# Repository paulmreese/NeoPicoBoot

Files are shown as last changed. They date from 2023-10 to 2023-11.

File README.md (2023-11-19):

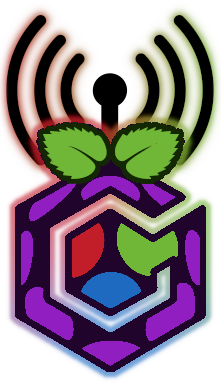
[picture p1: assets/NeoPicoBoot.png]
NeoPicoBoot Logo. A cubic raspberry logo with an antenna glowing red, green and blue


# NeoPicoBoot: NeoPixel + PicoBoot
This is an IPL replacement modchip for Nintendo GameCube. It's also a WiFi Access Point hosting responsive RGB control. It's open source, cheap, and easy to install.

## Features
* open source, easy to install
* uses $6 Raspberry Pi Pico W board
* RGB control for your controller ports and power LED
* easy-to-access NeoPixel web controls via Captive Portal
* boots any DOL app of your choice

<p align="center">
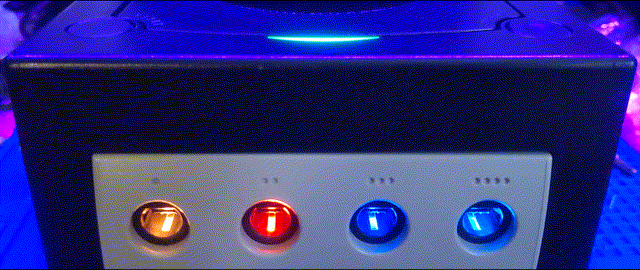
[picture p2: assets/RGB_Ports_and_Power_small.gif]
A zoomed-in view of a modded GameCube cycling a rainbow of colors in from the controller ports and power LED
  
</p>

## Installation guide

The complete installation guide has been moved to [a separate document](/INSTALLATION.md).

**A diode must be correctly installed between 5V and VSYS to prevent backflow. Connecting power to the USB port without a diode will destroy the power board, at minimum. Please mod carefully.**

Other than the NeoPixels being added, and **3V3** being swapped for **VSYS** from the 5V rail of the controller ports(through [a Schottky diode](https://www.amazon.com/dp/B0BYWPMRT1)), the wiring works exactly like the original. So, if you need any additional help you can head over to [the PicoBoot wiki](https://github.com/webhdx/PicoBoot/wiki) for [the PicoBoot Installation guide](../../wiki/Installation-guide).

Additionally, you can check the PicoBoot Discord Server to get support and discuss new features:



## Usage guide

The controls are designed to be as intuitive as possible. Take a look at the [Usage guide](USAGE.md) if you have any questions(or if you want to customize your network name or security).

## 3D Printed Parts
Printing these `STL` files makes for a much simpler installation process, but neither is necessary.

* [PicoBoot Mount for the Nintendo Gamecube](https://www.thingiverse.com/thing:5482506) - This mounts the Pico W onto the controller port board. While other mounts exist, this one is convenient for 2 reasons:
    1. The wires can exit the motherboard towards the controller ports, without deforming the RF shielding.
    2. The NeoPixels can be closer to the Pico W itself, with shorter wires.
* [NeoPixel alignment bracket](/assets/NeoPixel_Bracket.stl) - This bracket helps to align all of the controller port NeoPixels with the correct spacing. It will only install below the controller ports, if you have a normally installed battery. This can be printed in PLA and hot-glued into place.
  * This model was designed for a 0.4mm nozzle and 0.2mm layer height.

## Video guides and features overview

- [PicoBoot Modchip Will Unleash The POWER of Your Nintendo GAMECUBE! | Installation Guide and Overview](https://www.youtube.com/watch?v=qwL4ZSa0xMo) by [MachoNachoProductions](https://www.youtube.com/c/MachoNachoProductions)
- [This new Gamecube Modchip is a GAMECHANGER - PicoBoot](https://www.youtube.com/watch?v=lfMTLEM0yeQ) by [RockerGaming](https://www.youtube.com/c/RockerGaming)
- [$5 Gamecube IPL Modchip?! Picoboot Dol-001 + Dol-101 Installation / Setup / Showcase](https://www.youtube.com/watch?v=W_9-mSBMBJ4) by [ModzvilleUSA!](https://www.youtube.com/c/ModzvilleUSA)
- [PicoBoot GameCube custom mod chip - make and install your own chip with a Raspberry Pi Pico](https://youtu.be/rDrosSd-nDc) by [Joe Bleeps](https://www.youtube.com/@JoeBleeps)
- [RGB LED Mod Tutorial/ How to/ guide - Gamecube, Saturn, N64, SNES, and More!](https://youtu.be/1XUOI1c_viQ?si=Boch__JV7q4JWGpH) - This is a general RGB installation guide, but it does include GameCube

## Acknowledgements

Some parts of this project use GPL-2.0 licensed code from:
 * https://github.com/webhdx/PicoBoot
 * https://github.com/redolution/iplboot

Some parts of this project use MIT licensed code from:
 * https://github.com/sysprogs/PicoHTTPServer

Some parts of this project use LGPL-3.0 licensed code from:
 * https://github.com/martinkooij/pi-pico-adafruit-neopixels
 * https://github.com/adafruit/Adafruit_NeoPixel

## Hall of Fame

These are the people who made PicoBoot possible:
* [webhdx](https://github.com/webhdx) - All credit for the [PicoBoot](https://github.com/webhdx/PicoBoot) goes here. Consider being their [Sponsor](https://github.com/sponsors/webhdx)

* #gc-forever crew: [Extrems](https://github.com/Extrems), [novenary](https://github.com/9ary), [emu_kidid](https://github.com/emukidid) and others
* [tmbinc](https://github.com/tmbinc) - he started it all 🙏
* happy_bunny - [webhdx] started [webhdx's] research with his great writeup on [Shuriken Attack](https://www.retro-system.com/shuriken_attack.htm)
* PicoBoot beta testers: [seewood](https://github.com/seewood), [MethodOrMadness](https://github.com/MethodOrMadness), [renanbianchi](https://github.com/renanbianchi)
* content creators: [MachoNachoProductions](https://www.youtube.com/c/MachoNachoProductions), [RockerGaming](https://www.youtube.com/c/RockerGaming), [ModzvilleUSA!](https://www.youtube.com/c/ModzvilleUSA)
* people who sponsored [PicoBoot](https://github.com/webhdx/PicoBoot)
* every PicoBoot enjoyer - it's all about you after all 😉

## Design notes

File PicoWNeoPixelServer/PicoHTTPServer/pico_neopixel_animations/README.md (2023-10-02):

# Adafruit NeoPixel Animation Library for Pi PICO C/C++ SDK

Wrapper library for the Pi Pico Port of the Adafruit Library in a C/C++ SDK environment.
Built according to SDK standards as an INTERFACE library. In addition to functions and capabilities offered in the [original repo](https://github.com/martinkooij/pi-pico-adafruit-neopixels), this library allows the user to choose a custom animation order for a given NeoPixel(WS2812, etc.) strand, independent of the electrical order of the NeoPixel wiring. This enables easy control from an extrnal WiFi or Bluetooth library.

Friendly usage of pio statemachine implementations: Any NeoPixel object seizes sm and pio program space in a friendly, cooperative way.

The source library can be found in the main folder of this project (pico_neopixel_animations subdirectory). Adapt your project Makefile by using the command "add_subdirectory", then adding adding pico_neopixel_animations to the libraries of your project.

## Installation
Clone this repo to you local system using
````
git clone https://github.com/paulmreese/pico_neopixel_animations
````

## Building Examples
If the Pico SDK is installed according to its documentation, then the original examples should easily build.

Linux/Mac
````
cd pico_neopixel_animations/pi-pico-adafruit-neopixels/example
mkdir build && cd build
cmake ..
make
````
Windows
````
cd pico_neopixel_animations/pi-pico-adafruit-neopixels/example
mkdir build && cd build
cmake .. -G "NMake Makefiles"
nmake
````

The examples that work are `simple`, `strandtest_wheels` and ....
for the owner of the Maker PI PICO board of Cytron the example `onboard_cytron` that gives a nice colorful show on the built in NeoPixel (a strand of length 1 on PIN 28).

## Code Setup
NeoPixels may be connected to any GPIO pin. Once you are confident in the wiring and pin choices for your NeoPixel strand, you'll need to construct a `NeoPixelStrip` object to send instructions to, as shown:
1. Declare your LED pin, count(amount of LEDs), and pixel order. The `PIXEL_ORDER` defines the order the NeoPixels should follow, relative to the way they are electrically sequenced(The first NeoPixel of the electrical sequence would automatically be number "0", next is "1", etc.). **The string should terminate with a trailing space!!**
````
uint16_t LED_PIN =  28;
uint16_t LED_COUNT = 5;
std::string PIXEL_ORDER = "3 2 1 0 4 ";
````
2. Declare our `NeoPixelStrip` object(name `npStrip`):
````
NeoPixelStrip npStrip(LED_COUNT, LED_PIN, PIXEL_ORDER);
````
3. Send desired animation instructions:
````
npStrip.test_loop();
````

## Library documentation
This library is intended to provide animation functions that are easy to access from an external project. The available functions fall generally into two types: animation functions and their helper functions. An explanation of the purpose of each individual function is provided in the [header file of this project](pico_neopixel_animations.h)

## Resources specific to the Adafruit Neopixel library
See [the Adafruit Neopixel library documentation](https://github.com/adafruit/Adafruit_NeoPixel) for more information specific to it.

## Resources specific to the Adafruit Pi Pico port
[The original repo](https://github.com/martinkooij/pi-pico-adafruit-neopixels) contains more specific implementation details.

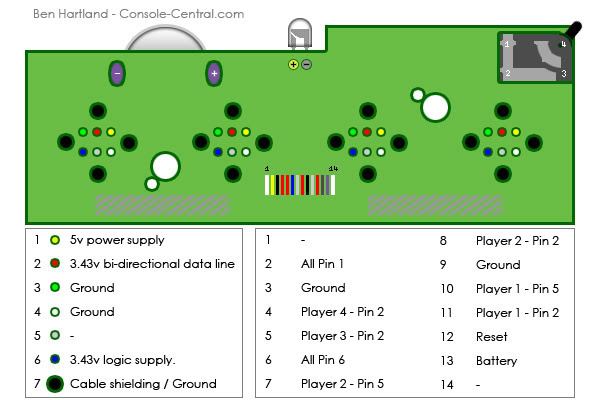
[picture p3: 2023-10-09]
assets/gamecubecontrollerboard.jpeg

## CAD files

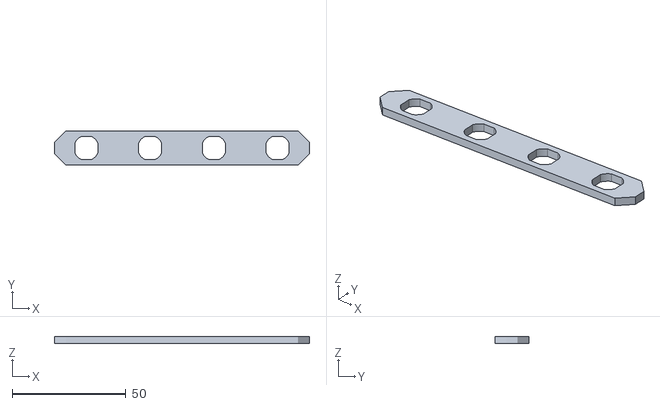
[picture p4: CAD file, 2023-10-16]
assets/NeoPixel_Bracket.stl
112.0 x 15.0 x 3.00

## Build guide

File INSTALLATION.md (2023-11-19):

# NeoPicoBoot: NeoPixel + PicoBoot

## Installation guide

<p align="center">
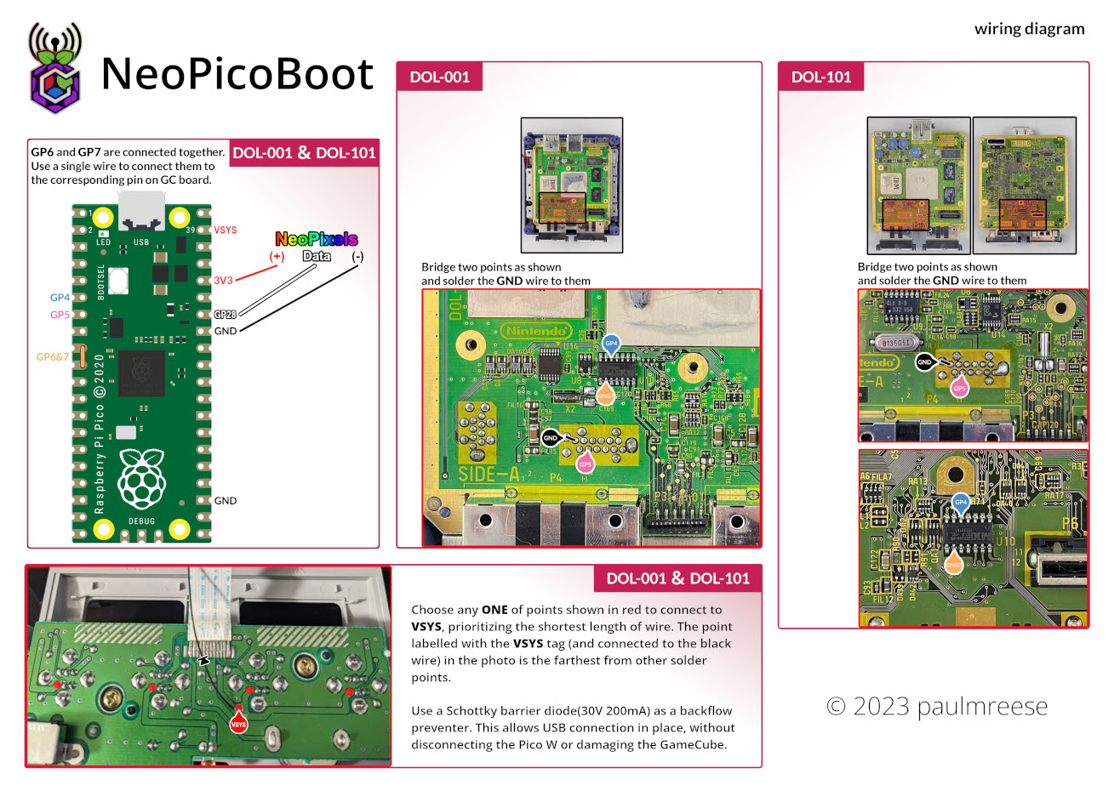
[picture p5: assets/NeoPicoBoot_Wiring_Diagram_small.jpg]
NeoPicoBoot Wiring Diagram
  
  <i>
    A visual installation guide to show wiring connections
  </i>
</p>

**A diode must be correctly installed between 5V and VSYS to prevent backflow. Connecting power to the USB port without a diode will destroy the power board, at minimum. Please mod carefully.**

This should be enough information to guide someone through a basic installation. [A larger version of the image](/assets/NeoPicoBoot_Wiring_Diagram.jpg) is also included with this repo. This wiring incorporates [a method mentioned in an issue on the original PicoBoot Repo](https://github.com/webhdx/PicoBoot/issues/75#issuecomment-1539225503), which wires power into the **VSYS** pin of the Pico W through [a Schottky diode](https://www.amazon.com/dp/B0BYWPMRT1), instead of being directly wired to the **3V3** pin.

According to the [Raspberry Pi Pico W Datasheet](https://datasheets.raspberrypi.com/picow/pico-w-datasheet.pdf):
> VSYS is the main system input voltage, which can vary in the allowed range 1.8V to 5.5V, and is used by the on-board SMPS to generate the 3.3V for the RP2040 and its GPIO.

> 3V3 is the main 3.3V supply to RP2040 and its I/O, generated by the on-board SMPS. This pin can be used to power external circuitry (maximum output current will depend on RP2040 load and VSYS voltage; it is recommended to keep the load on this pin under 300mA).

### RGB
As for the NeoPixels(WS2812, etc), this [video shows exactly how to mod your controller port board to add the NeoPixels](https://youtu.be/1XUOI1c_viQ?si=Boch__JV7q4JWGpH)
<p align="center">
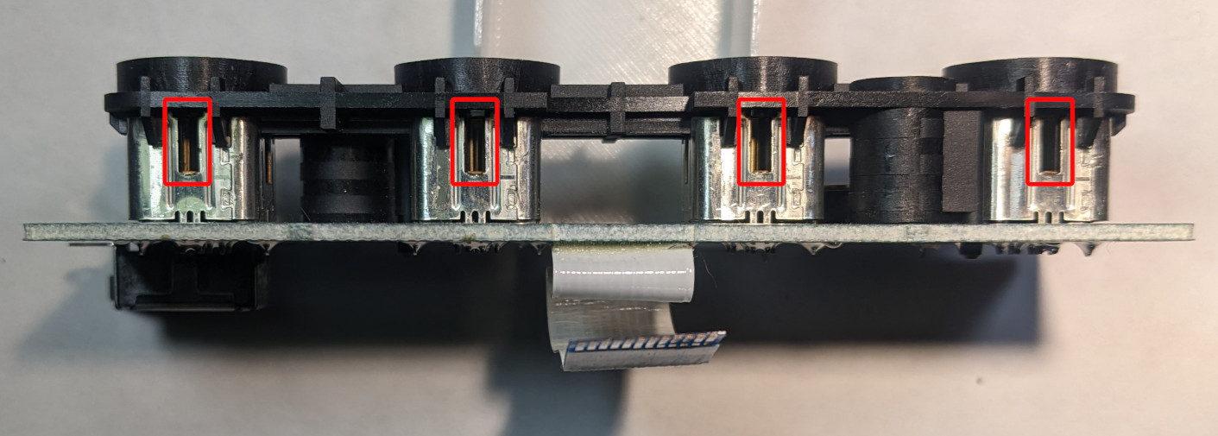
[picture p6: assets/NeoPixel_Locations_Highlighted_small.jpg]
View of the GameCube controller port PCB from below, with the center retaining pins removed(highlighted in red).
  
  <i>GameCube controller ports from below, with retaining pins removed</i>
</p>

* [1:04](https://youtu.be/1XUOI1c_viQ?si=35ieH2EPR0lPXH_Q&t=64) - Remove the pins from each port. These pins can be removed from **either** the top *or* the bottom of each controller port. These LEDs can be very bright, so choose based on where you keep your GameCube. I personally use tweezers to snap the bottom ones so that I'm not competing with the battery for space.
<p align="center">
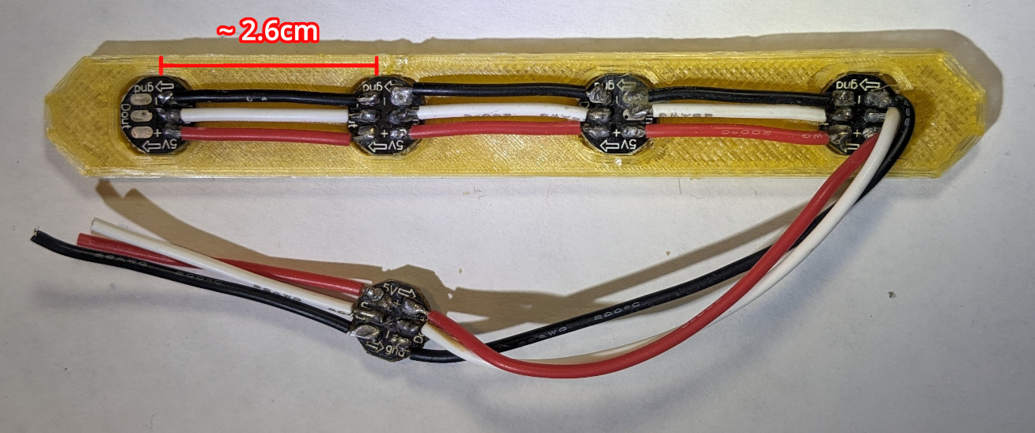
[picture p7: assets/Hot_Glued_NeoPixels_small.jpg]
Five NeoPixels wired together in a chain, with four of them hot-glued into a 3d-printed bracket.
  
  <i>Wired NeoPixels set in their <a href="/assets/NeoPixel_Bracket.stl">3D-printed bracket</a></i>
</p>

* [3:25](https://youtu.be/1XUOI1c_viQ?si=mzvSUIralLa4HMga&t=205) - Create a strand of 5 NeoPixels. Make sure to leave a little bit of slack in the wires between each NeoPixel, especially to the power led and Pico W. Make sure the arrows on your NeoPixels point the same direction, and check continuity on the positive and negative wires regularly!
<p align="center">
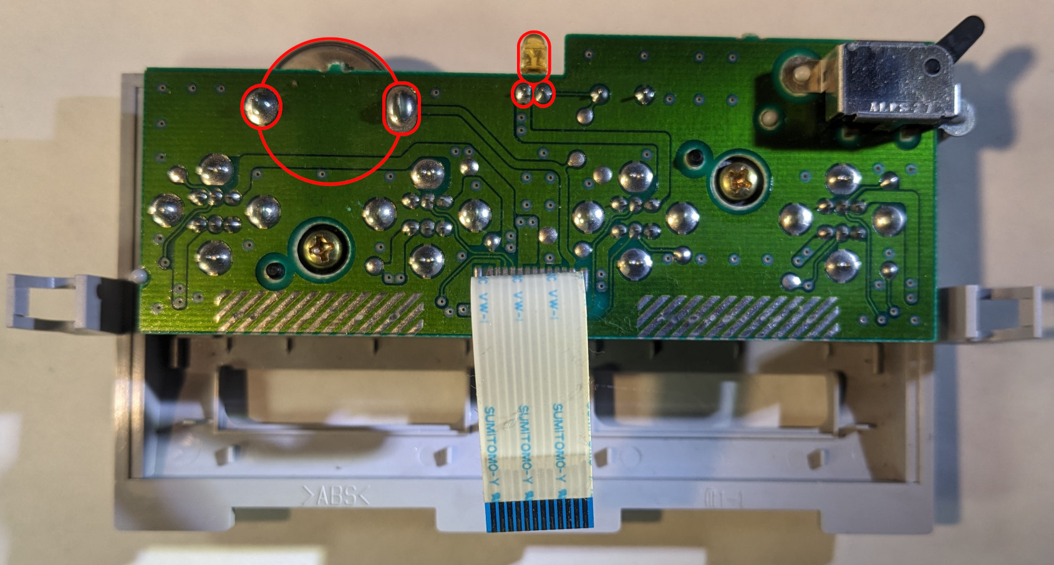
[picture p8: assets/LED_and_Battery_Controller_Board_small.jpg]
View of the GameCube controller port PCB from the back, highlighting the pins of the power LED and Battery
  
  <i>Battery and power LED solder points</i>
</p>

* [5:50](https://youtu.be/1XUOI1c_viQ?si=wtnrG3PIRv7RvrTk&t=350) - Remove stock LED. Optionally, also replace CR2032 Clock Battery. I would highly recommend replacing this battery with a separate battery holder and fresh battery.
<p align="center">
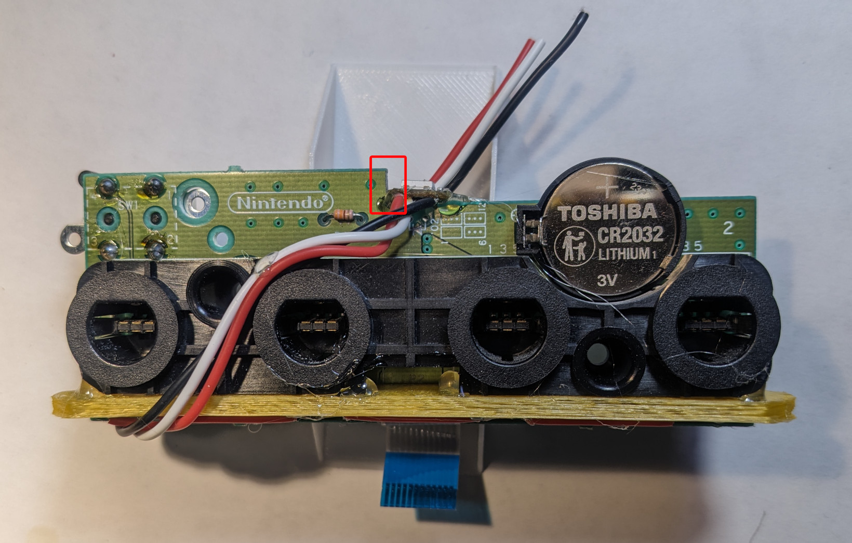
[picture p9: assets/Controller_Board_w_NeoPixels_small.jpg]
View of the GameCube controller port PCB from the front, with the sanded/filed-away area highlighted. A new battery holder with a new battery is shown.
  
  <i>The highlighted area has been sanded away. Note the new battery holder</i>
</p>

* [6:25](https://youtu.be/1XUOI1c_viQ?si=p0bYnIFZQqc9hqtQ&t=385) - Hot glue controller port NeoPixels into place. Make sure they all point the same angle! You can remove the hot glue with rubbing alcohol. I've included [a 3D model of a basic alignment bracket as an STL file](/assets/NeoPixel_Bracket.stl) if you have access to a 3D printer. This bracket will only install below the controller ports, if you have a normally installed battery.

* [8:00](https://youtu.be/1XUOI1c_viQ?si=zBVIya90WfhzKUA-&t=480) - Hot glue Power NeoPixel. In my experience, you often need to seat the power LED lower than shown in the video for it to align correctly with the original light pipe. I recommend seating to the bottom of the notch on the PCB. This can sometimes involve sanding the PCB to the side to fit a NeoPixel.
<p align="center">
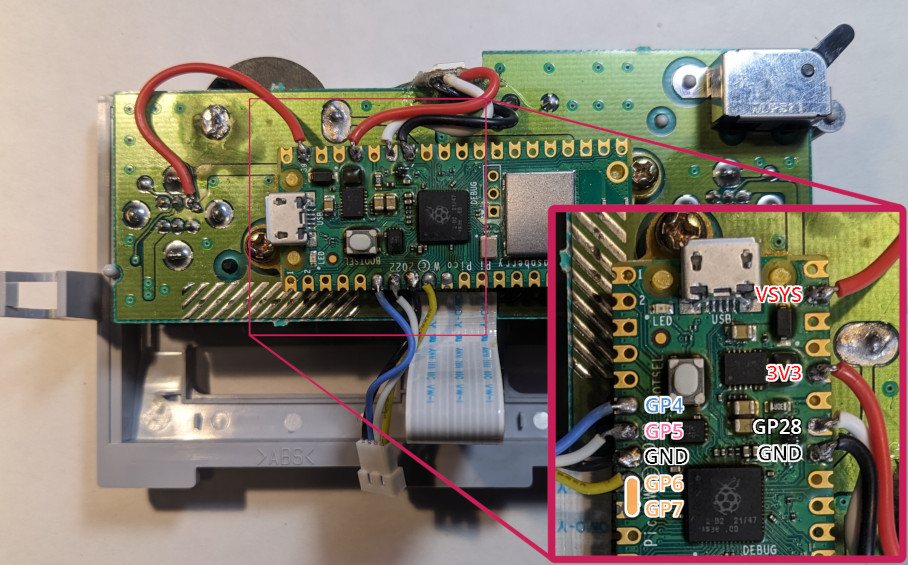
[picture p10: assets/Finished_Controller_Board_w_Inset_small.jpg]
View of the GameCube controller port PCB from the back, with the Pico W wired to the NeoPixels, the 5V rail of GameCube, and wires to connect to the GameCube motherboard
  
  <i>Pico W mounted to the controller port board with wires connecting to the NeoPixels, 5V power, and motherboard(for PicoBoot)</i>
</p>

Other than the NeoPixels being added, and **3V3** being swapped for **VSYS** from the 5V rail of the controller ports, the wiring works exactly like the original. So, if you need any additional help you can head over to [the PicoBoot wiki](https://github.com/webhdx/PicoBoot/wiki) for [the PicoBoot Installation guide](../../wiki/Installation-guide).

Additionally, you can check the PicoBoot Discord Server to get support and discuss new features:



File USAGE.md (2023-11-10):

# Usage Guide

The NeoPicoBoot web interface is designed to be as straightforward to use as possible. This guide explains the features and their usage. If you would like to request additional patterns or animations, please submit a feature request to this repository.

## Network Name and Password

NeoPicoBoot uses the Captive Portal method broadcasting a network as a dedicated WiFi Access Point. By default, this network will have the default SSID of `GC_RGB` and no password.

These values can be altered in [the CMakeLists.txt file in the PicoWNeoPixelServer/PicoHTTPServer directory](https://github.com/paulmreese/NeoPicoBoot/blob/686e2f957be58c4621f378fb9fc77a336fcbb2db/PicoWNeoPixelServer/PicoHTTPServer/CMakeLists.txt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). You can substitute any valid name for the network SSID you prefer. To add a password, just uncomment `set(WIFI_PASSWORD 12345678)` and replace `12345678` with that password. You'll need to recompile the firmware if you change these settings. The remainder of this guide will refer to the default settings.

## Connecting

When you start up the Pico W after installing the firmware(or when you startup your GameCube with the mod installed), a startup animation sequence will display on the NeoPixels. This happens after the PicoBoot code has successfully run. The display occurs as the server is initialized. You can now use any WiFi-enabled device to access the `GC_RGB` network, which will initiate the Captive Portal process. For most modern phones, you'll be given the option to `Sign into network`(or similar wording) as a notification. On many devices the control page will automatically appear upon your attempted connection.

### Troubleshooting Connection

Some devices may notice that this network offers no internet access and balk at any connection attempts. In this case there is often an option to `Connect Anyways` within the network-specific settings. This may require that the device remembers the network for next usage. Please submit any connection issues you encounter to this repo.

## Control

The controls are presented as a responsive web app, and as the result of this approach will differ between different systems. If you encounter any issues interacting with the controls, please let me know!

<p align=center>
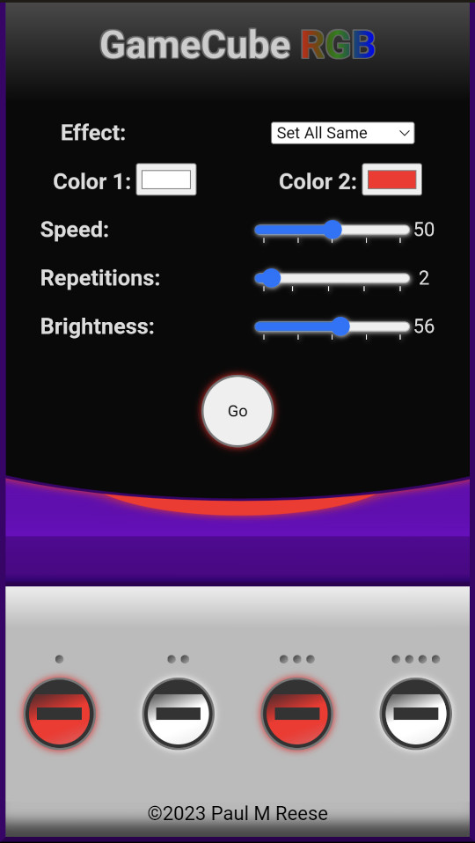
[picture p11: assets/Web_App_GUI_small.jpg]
A screen shot of the GameCube RGB interface of NeoPicoBoot
  
</p>

For any individual LED on the system, you can click or tap the corresponding location to bring up a color picker to set a new color. The color will fade from the current color to the chosen color.

For patterns of animation affecting all NeoPixels, you'll first need to select the relevant animation from the Effect drop-down. This will activate any options that would be used by the particular animation. Next, you'll need to set the desired colors, repetitions, speed, and/or brightness. Once you've chosen your values, click `Go`!

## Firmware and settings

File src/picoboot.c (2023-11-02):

/**
 * Copyright (c) 2022 Maciej Kobus
 * Original code licensed under
 * SPDX-License-Identifier: GPL-2.0-only
 * All additional code licensed under GPL-3.0
 */
#include <stdio.h>
#include "pico/stdlib.h"
//#include "pico/cyw43_arch.h"
#include "hardware/pio.h"
#include "hardware/clocks.h"
#include "hardware/dma.h"
#include "hardware/structs/bus_ctrl.h"
#include "picoboot.pio.h"
#include "ipl.h"
#include "PicoWNeoPixelServer/PicoHTTPServer/picow_neopixel_server.h"

//This requires the use of the Wifi chip
    // on a Pico W. This code would be called where WiFi is initialized
//const uint PIN_LED = 25;                // Status LED
const uint PIN_DATA_BASE = 6;           // Base pin used for output, 4 consecutive pins are used 
const uint PIN_CS = 4;                 // U10 chip select
const uint PIN_CLK = 5;                // EXI bus clock line

// __no_inline_not_in_flash_func to load from RAM
void __no_inline_not_in_flash_func(main_contents)(void)
{
    
    // Initialize and light up builtin LED, it will basically
    // act as a power LED. This should be done in the main.cpp file,
    // if at all. 
    // TODO: Use the LED to signalize system faults?
    // pmr - The NeoPixels could communicate error state 
    
    
    // Set 250MHz clock to get more cycles in between CLK pulses.
    // This is the lowest value I was able to make the code work.
    // Should be still considered safe for most Pico boards.
    set_sys_clock_khz(250000, true);

    // Prioritize DMA engine as it does the most work
    bus_ctrl_hw->priority = BUSCTRL_BUS_PRIORITY_DMA_W_BITS | BUSCTRL_BUS_PRIORITY_DMA_R_BITS;

    gpio_set_slew_rate(PIN_DATA_BASE, GPIO_SLEW_RATE_FAST);
    gpio_set_slew_rate(PIN_DATA_BASE + 1, GPIO_SLEW_RATE_FAST);
    gpio_set_slew_rate(PIN_DATA_BASE + 2, GPIO_SLEW_RATE_FAST);
    gpio_set_slew_rate(PIN_DATA_BASE + 3, GPIO_SLEW_RATE_FAST);

    gpio_set_drive_strength(PIN_DATA_BASE, GPIO_DRIVE_STRENGTH_4MA);
    gpio_set_drive_strength(PIN_DATA_BASE + 1, GPIO_DRIVE_STRENGTH_4MA);
    gpio_set_drive_strength(PIN_DATA_BASE + 2, GPIO_DRIVE_STRENGTH_4MA);
    gpio_set_drive_strength(PIN_DATA_BASE + 3, GPIO_DRIVE_STRENGTH_4MA);

    PIO pio = pio0;

    //
    // State Machine: Transfer Start
    //
    // Counts all consecutive transfers and sets IRQ 
    // when first 1 kilobyte transfer starts.
    //

    uint transfer_start_sm = pio_claim_unused_sm(pio, true);
    uint transfer_start_offset = pio_add_program(pio, &on_transfer_program);

    on_transfer_program_init(pio, transfer_start_sm, transfer_start_offset, PIN_CLK, PIN_CS, PIN_DATA_BASE);

    pio_sm_put(pio, transfer_start_sm, (uint32_t) 224); // CS pulses
    pio_sm_exec(pio, transfer_start_sm, pio_encode_pull(true, true));
    pio_sm_exec(pio, transfer_start_sm, pio_encode_mov(pio_x, pio_osr));
    pio_sm_exec(pio, transfer_start_sm, pio_encode_out(pio_null, 32));

    //
    // State Machine: Clocked Output
    // 
    // It waits for IRQ signal from first SM and samples clock signal
    // to output IPL data bits.
    //

    uint clocked_output_sm = pio_claim_unused_sm(pio, true);
    uint clocked_output_offset = pio_add_program(pio, &clocked_output_program);

    clocked_output_program_init(pio, clocked_output_sm, clocked_output_offset, PIN_DATA_BASE, PIN_CLK, PIN_CS);

    pio_sm_put(pio, clocked_output_sm, 8191); // 8192 bits, 1024 bytes, minus 1 because counting starts from 0 
    pio_sm_exec(pio, clocked_output_sm, pio_encode_pull(true, true));
    pio_sm_exec(pio, clocked_output_sm, pio_encode_mov(pio_y, pio_osr));
    pio_sm_exec(pio, clocked_output_sm, pio_encode_out(pio_null, 32));

    // Set up DMA for reading IPL to PIO FIFO
    int chan = dma_claim_unused_channel(true);

    dma_channel_config c = dma_channel_get_default_config(chan);
    channel_config_set_transfer_data_size(&c, DMA_SIZE_32);
    channel_config_set_read_increment(&c, true);
    channel_config_set_write_increment(&c, false);
    channel_config_set_dreq(&c, pio_get_dreq(pio, clocked_output_sm, true));

    dma_channel_configure(
        chan,
        &c,
        &pio->txf[clocked_output_sm],
        ipl,
        count_of(ipl),
        true // start immediately
    );

    // Start PIO state machines
    pio_sm_set_enabled(pio, transfer_start_sm, true);
    pio_sm_set_enabled(pio, clocked_output_sm, true);

    bool server_has_started = false;

    while (true) {
        tight_loop_contents();
        if (!server_has_started) {
            launch_server();
        }
    }
}

void main() {
    main_contents();
}

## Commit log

2023-10-16 Add NeoPixel bracket STL
    [NeoPixel_Bracket.stl]
2023-10-18 Squashed 'PicoWNeoPixelServer/' changes from 08f0088..6ea681c
    6ea681c Update pixel_order to match shorter wiring route
    5ce30ed Prevent SimpleFSBuilder duplicate build
    b99ddf3 Separate build scripts
    git-subtree-dir: PicoWNeoPixelServer
    git-subtree-split: 6ea681c447d72f2fed93070c5d3fe9a3b29bdd86
    [main.cpp]
2023-10-18 Fix stl link
2023-11-19 Add 3D printer settings
2023-11-19 Add Schottky diode to documentation
